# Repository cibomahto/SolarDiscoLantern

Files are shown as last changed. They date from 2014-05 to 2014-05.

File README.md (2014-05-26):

Solar Disco Lantern
===================

A disco twist on the traditional solar lantern, this little guy will light your way at night, and bounce to your music!

An all-analog circuit makes for a low-power and low-cost design.

The solar charging circuit is based on the Kimono Lantern Kit by Akiba:
http://www.tokyohackerspace.org/en/project/kimono-lantern

Designed by Honghong and Matt for Dragon Burn 2014

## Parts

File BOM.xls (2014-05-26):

Quantity | Designator | Desc | Package | Got?
2 | D3, D4 | 1N4148 | SOT-23
3 | T1, T2, T3 | 2n2222 | SOT-23
1 | BAT1 | Battery holder | AAA thru-hole
1 | C4 | .1uF | 603
2 | C1, C7 | 100uF | 603
3 | C2, C3, C5 | 1uF | 603
1 | C6 | 22uF | 603
2 | ON/OFF, GAIN | DPDT SMT switch
1 | R10 | 100K | 603
1 | U2 | HT7733A | SOT-89
1 | L1 | 100uH | 805
1 | LED1 | LED purple | 5mm
1 | LED2 | LED white | 5mm
1 | U$1 | MIC
2 | R1, R4 | 1.2k | 603
2 | R3, R14 | 100 | 603
2 | R15, R16 | 10k | 603
2 | R2, R9 | 1k | 603
4 | R5, R7, R11, R12 | 1M | 603
2 | R6, R8 | 39k | 603
1 | R13 | 600 | 603
1 | D1 | See lantern circuit | SOT-23
1 | T5 | 2SA950 | SOT-23
1 | T4 | 2SAC2120Y | SOT-23
1 | D2 | See lantern circuit | SOT-23
1 |  | Solar Cell, 80mA, 2V Futurelec SZGDDIA58
1 |  | Battery, NiMH AAA 1.2V

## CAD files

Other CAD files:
snowflake.SLDPRT
snowflake.DXF

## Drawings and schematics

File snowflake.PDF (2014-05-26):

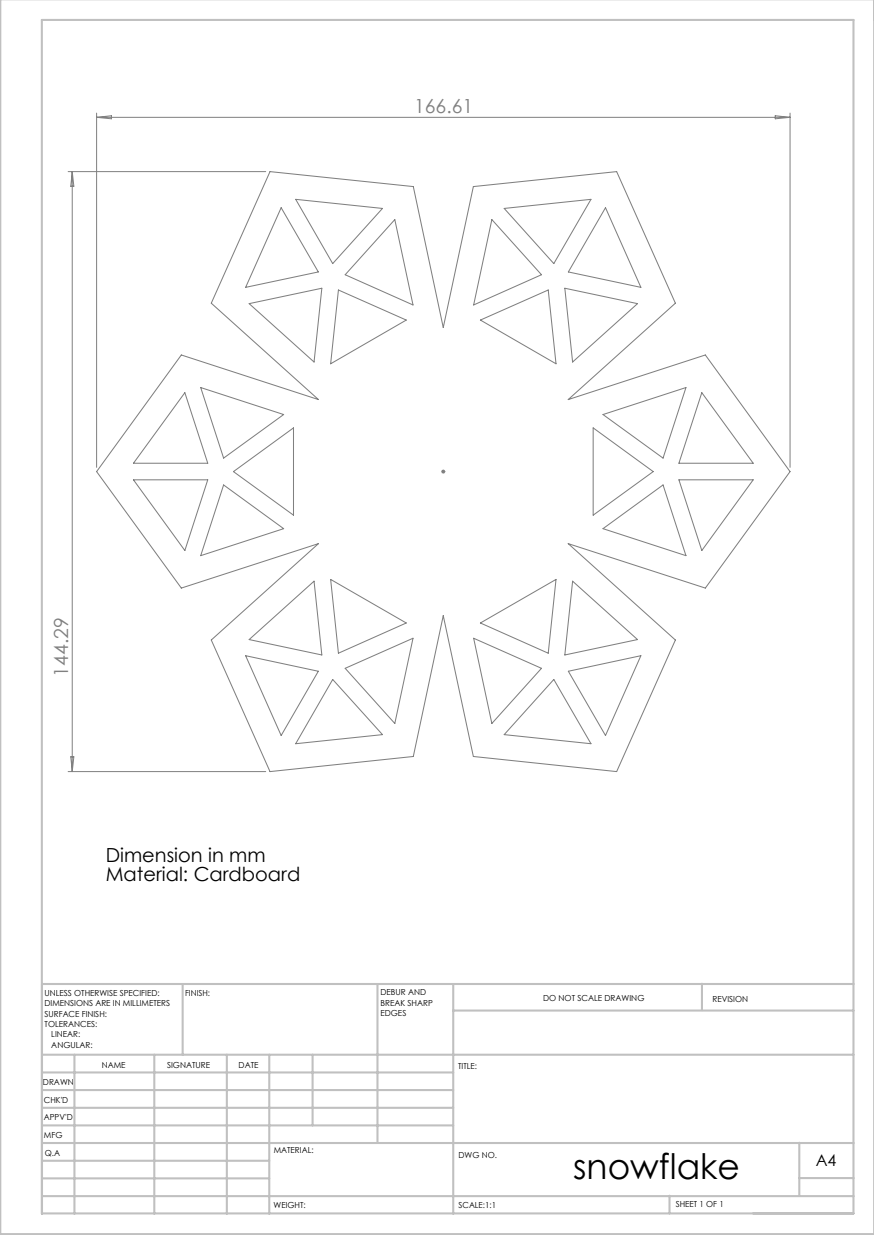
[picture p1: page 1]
SCALE:1:1; SHEET 1 OF 1; DO NOT SCALE DRAWING; REVISION; DEBUR AND BREAK SHARP; UNLESS OTHERWISE SPECIFIED:; FINISH:

Dimension in mm
Material: Cardboard

DIMENSIONS ARE IN MILLIMETERS
SURFACE FINISH:
TOLERANCES:
LINEAR:
ANGULAR:

NAME | SIGNATURE | DATE | | | | TITLE:
Q.A | | | | MATERIAL: | snowflake WEIGHT: DWG NO. | A4

DRAWN
CHK'D
APPV'D
MFG

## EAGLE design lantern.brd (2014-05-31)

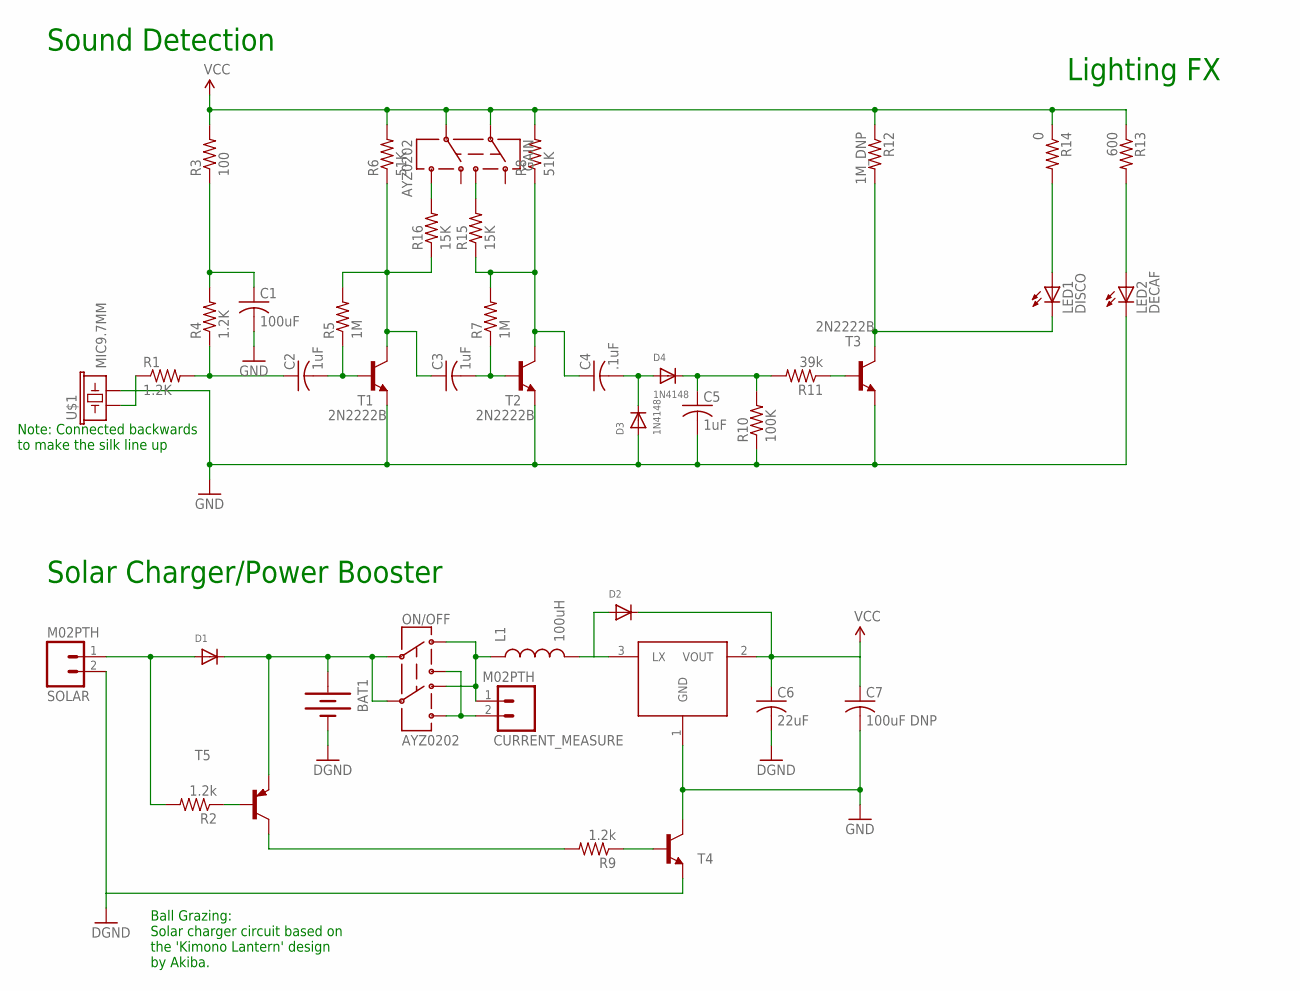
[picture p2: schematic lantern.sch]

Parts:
BAT1: BATTERYAAA; BATTERY-AAA
C1: 100uF; C1210
C2, C3, C5: 1uF; C0603
C4: .1uF; C0603
C6: 22uF; C0603
C7: 100uF DNP; C1210
CURRENT_MEASURE: M02PTH; 1X02
D1, D2: DIODESOT23_REFLOW; SOT23-R
D3, D4: 1N4148; SOT23-R
GAIN: AYZ0202
L1: 100uH; 0805
LED1: DISCO; LED5MM
LED2: DECAF; LED5MM
ON/OFF: AYZ0202
R1, R4: 1.2K; R0603
R2, R9: 1.2k; R0603
R3: 100; R0603
R5, R7: 1M; R0603
R6, R8: 51K; R0603
R10: 100K; R0603
R11: 39k; R0603
R12: 1M_DNP; R0603
R13: 600; R0603
R14: 0; R0603
R15, R16: 15K; R0603
SOLAR: M02PTH; 1X02
T1, T2, T3, T4: 2N2222B; SOT23
T5: 2N2907B; SOT23
U2: HT7733A; SOT89
U$1: MIC9.7MM; MIC-9.7MM

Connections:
DGND: BAT1.GND@1 (-), C6.2, SOLAR.2, T4.2 (E)
GND: C1.2, C5.2, C7.2, D3.1 (A), LED2.K (C), R10.1, T1.2 (E), T2.2 (E), T3.2 (E), T4.3 (C), U2.1 (GND), U$1.2
unnamed: C2.1, R1.2, R4.1
unnamed: C1.1, R3.1, R4.2
unnamed: C2.2, R5.1, T1.1 (B)
unnamed: C3.1, R5.2, R6.1, R16.1, T1.3 (C)
unnamed: C4.1, R7.2, R8.1, R15.1, T2.3 (C)
unnamed: C3.2, R7.1, T2.1 (B)
unnamed: R1.1, U$1.1
unnamed: LED1.K (C), R12.2, T3.3 (C)
unnamed: R11.1, T3.1 (B)
unnamed: C4.2, D3.3 (C), D4.1 (A)
unnamed: D1.1 (A), R2.2, SOLAR.1
unnamed: C5.1, D4.3 (C), R10.2, R11.2
unnamed: R9.2, T5.3 (C)
unnamed: R9.1, T4.1 (B)
unnamed: BAT1.PWR@1 (+), D1.3 (C), ON/OFF.2, ON/OFF.5, T5.2 (E)
unnamed: R2.1, T5.1 (B)
unnamed: CURRENT_MEASURE.1, L1.1, ON/OFF.3 (1), ON/OFF.6 (4)
unnamed: D2.1 (A), L1.2, U2.3 (LX)
unnamed: LED2.A, R13.2
unnamed: LED1.A, R14.2
unnamed: CURRENT_MEASURE.2, ON/OFF.1 (3), ON/OFF.4 (6)
unnamed: GAIN.4 (6), R16.2
unnamed: GAIN.1 (3), R15.2
VCC: C6.1, C7.1, D2.3 (C), GAIN.2, GAIN.5, R3.2, R6.2, R8.2, R12.1, R13.1, R14.1, U2.2 (VOUT)

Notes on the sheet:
Solar Charger/Power Booster
Sound Detection
Lighting FX
Ball Grazing: Solar charger circuit based on the 'Kimono Lantern' design by Akiba.
Note: Connected backwards to make the silk line up

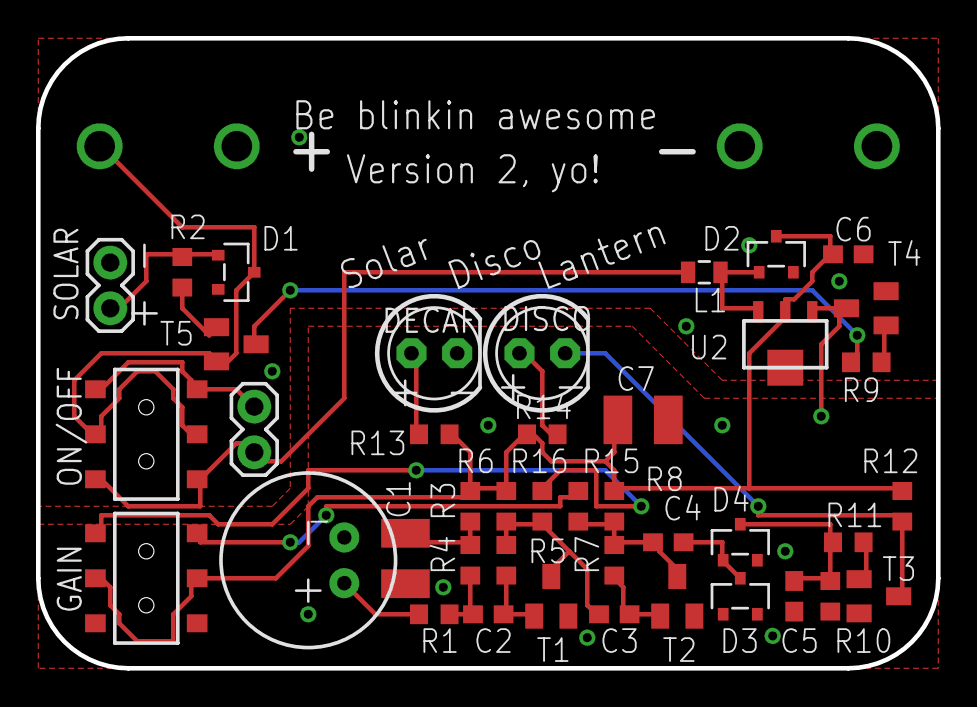
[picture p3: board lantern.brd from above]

Board: 2 copper layers, 50.0 x 35.0 mm, 42 parts (0 on the bottom side), 26 nets.

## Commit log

2014-05-23 Add lantern
    [lantern.brd, lantern.sch]
2014-05-24 RevA pcb finished, first case version
    [lantern.brd, lantern.sch, snowflake.DXF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]
2014-05-26 Add BOM and solidwords drawing for case
    [BOM.xls]
2014-05-31 Small updates for RevB, change capacitor size and fix some labels. Hope it works!
    [lantern.brd, lantern.sch]

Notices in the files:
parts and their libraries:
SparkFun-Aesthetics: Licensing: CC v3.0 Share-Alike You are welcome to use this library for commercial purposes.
